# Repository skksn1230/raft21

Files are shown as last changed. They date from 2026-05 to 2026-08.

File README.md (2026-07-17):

# raft21（ソクタイプ型のDIYキーボード）
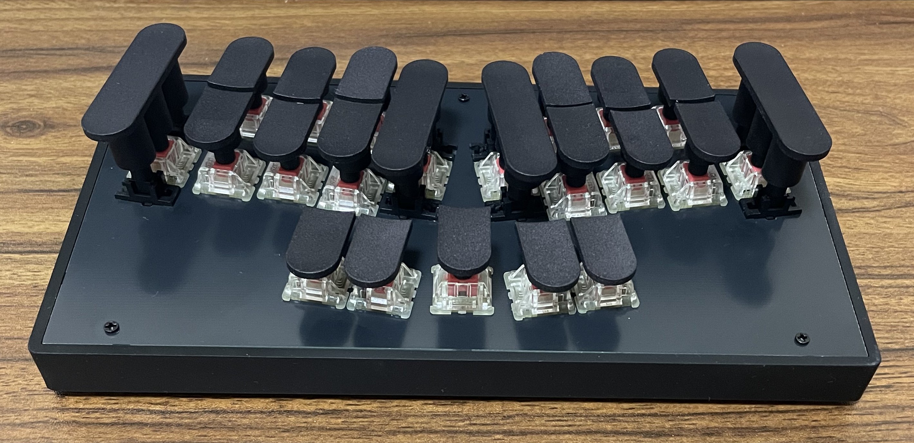
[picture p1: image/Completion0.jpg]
Completion

## 概要
raft21はStenturaプロトコル互換で動くソクタイプ型のDIYキーボードです。  
ソクタイプは21キーで、キーの配置やキーキャップのサイズ、表面のくぼみ、高低差があるなどの特徴があります。  
Ploverでの動作は確認できましたが、Stenturaプロトコルと同一のものではありません。  
実機などから情報を得てStenturaプロトコルを再現したということはありません。  
また、キーキャップのサイズなどに関して、ソクタイプの厳密な再現とは言えない可能性があります。  
## PCB基盤
KiCadを使用して作成。MCUはRP2040（Raspberry Pi Pico）を使用します。  
MCUはピンヘッダを使わない直接はんだ付け、基盤の厚さは1.6mm厚の前提でケースを設計しています。
## スイッチプレート
KiCadを使用して作成。基盤を発注するのと同様に発注します。1.6mm厚の前提でケースは作成しています。
## キーキャップ
ソクタイプ型のキーキャップを再現するために3Dプリンターで作成します。
（一番上の画像のキーキャップでは、JLC3DCPに発注した「PA12S-HP Nylon」という素材を使用しています。３Ｄプリンターの特性上、ステム（軸）のサイズが多少設計と異なる可能性があるため、弾力性のある素材を使用したいという意図もあり、ナイロン素材を採用しました。）
## ケース
3Dプリンターで作成します。`bottom-case.stl`
（一番上の画像のケースでは、JLC3DCPに発注した「JLC Black Resin」という素材を使用しています。一度、キーキャップと同じナイロン素材も試したことがありますが、反りが出てしまいました。「JLC Black Resin」では反りは出ませんでした）
## 製作に必要なもの（上記以外）
| 名称　　　　  | 個数　　　　  | 備考 　　　　 
|:---:|:---:|:---:|
| Raspberry Pi Pico  | 1 | Pico 2 ではない |
| PCBソケット  | 21 |スイッチを直接はんだ付けするなら不要|
| Cherry MX互換スイッチ  | 21 | 赤軸静音推奨　　　　 |
| プレートマウントスタビライザー 2U | 4 | MX用（PCBマウントではない） |
| M2 6mm ねじ | 14 | 天用・底用ねじ |
| M2 8mm スペーサー  | 7 | 外径4.0mm以下 |
| Micro USB ケーブル  | 1 | データ転送対応のもの |
| ゴム足 10mm  | 4 | 　高さ任意　　　 |

※PCBソケット（使用しないならキースイッチ）と Raspberry Pi PicoをPCB基盤にはんだ付けする必要があります。

※両手の人差し指側につけるスタビライザーは、接触する箇所があります。  
　適宜ニッパー等でカットし、接触しないようにする必要があります。
 静音フォームなども、キースイッチ間の距離が短いため、適宜加工する必要があるかもしれません。

※キースイッチとばねをルブ（潤滑）するなら、キースイッチ用とばね用の潤滑剤が必要です。

※キースイッチのばねを取り替えるなら、それも必要です。   
　23g 22mmは正常に動く中では軽い設定ですが、長期の使用に耐えるかは不明です。
 30g以上のほうが、安心して使えるかもしれません。

## uf2ファイル
BOOTSELボタンを押しながらUSBケーブルを接続し、Raspberry Pi Picoを書き込みモードで立ち上げ、そのフォルダ内にuf2ファイルをコピーすることで書き込みできます。

## 作業手順
- [大まかな作業手順](https://github.com/skksn1230/raft21/tree/main/image/README.md)  

## 参考
- [Plover](https://github.com/opensteno/plover)  
- [電子速記研究会 （はやとくんの会）](https://www.hayatokun.com/)
- [電子速記はやとくん](https://www.youtube.com/@%E9%9B%BB%E5%AD%90%E9%80%9F%E8%A8%98%E3%81%AF%E3%82%84%E3%81%A8%E3%81%8F%E3%82%93/shorts)

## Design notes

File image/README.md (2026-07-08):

### ソケットのはんだ付け
PCBの裏面に、ソケットをはんだ付けします。
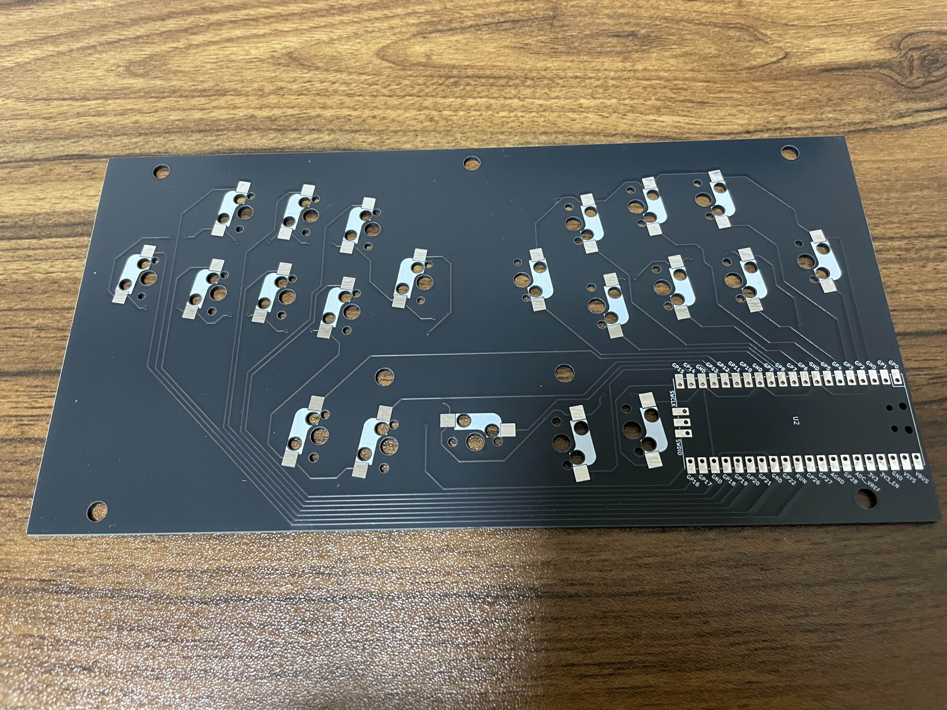
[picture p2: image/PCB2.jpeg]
PCB2

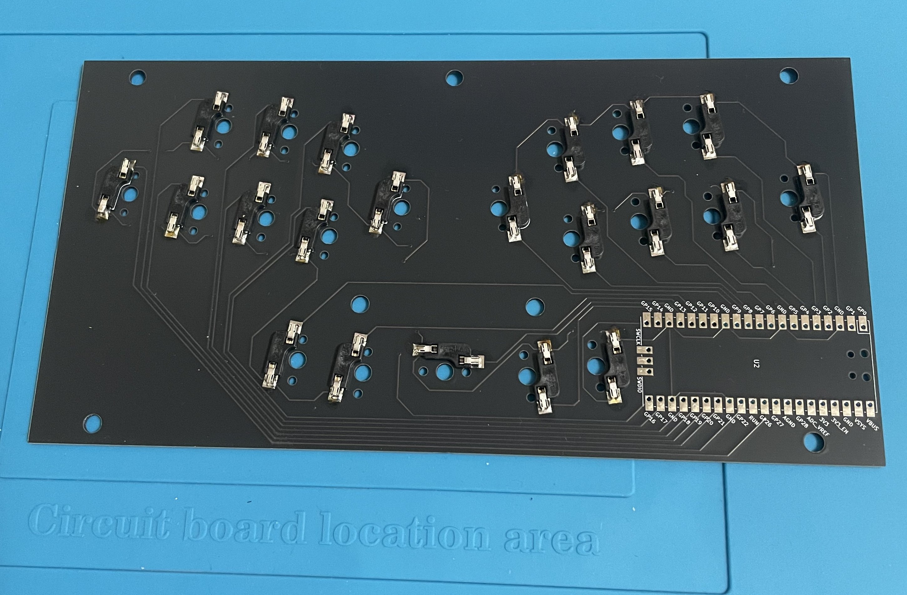
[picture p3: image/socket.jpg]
socket

### MCUのはんだ付け
３つの角を仮止め（図はピンヘッダを１つ折って使用している）して、４つ目の角をはんだ付けします。
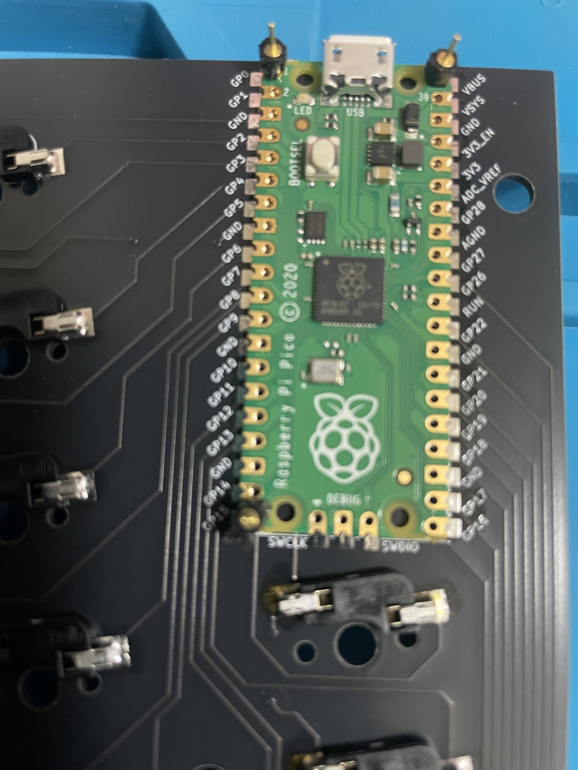
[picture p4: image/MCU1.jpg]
MCU1

１つの角（図では右下）をはんだ付けできたら、同様にほかの角もはんだ付けします。
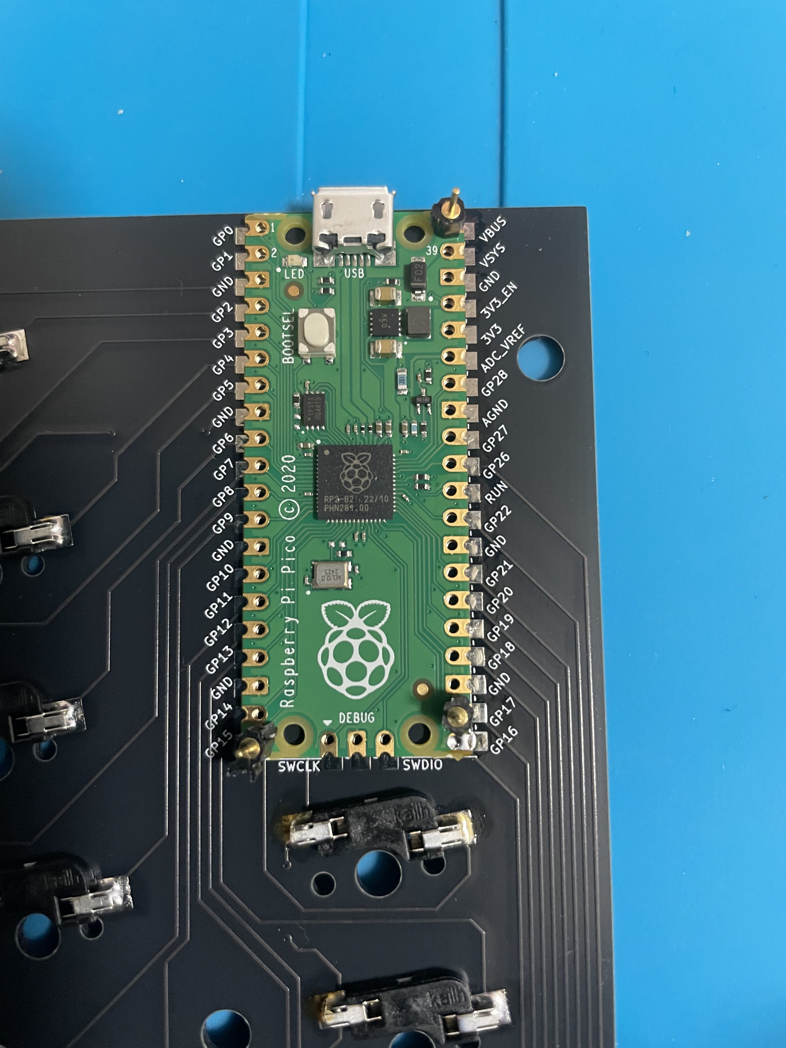
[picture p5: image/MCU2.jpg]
MCU2

４つの角だけはんだ付けできた状態。
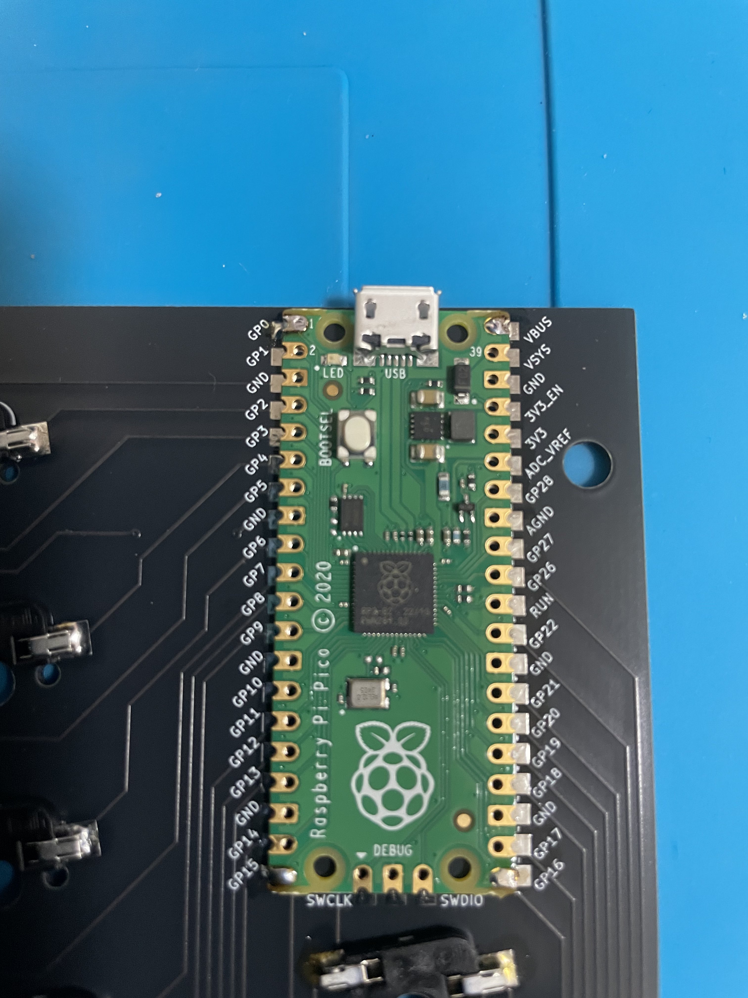
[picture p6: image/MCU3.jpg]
MCU3

四隅からちょっとずつはんだ付けしていきます。
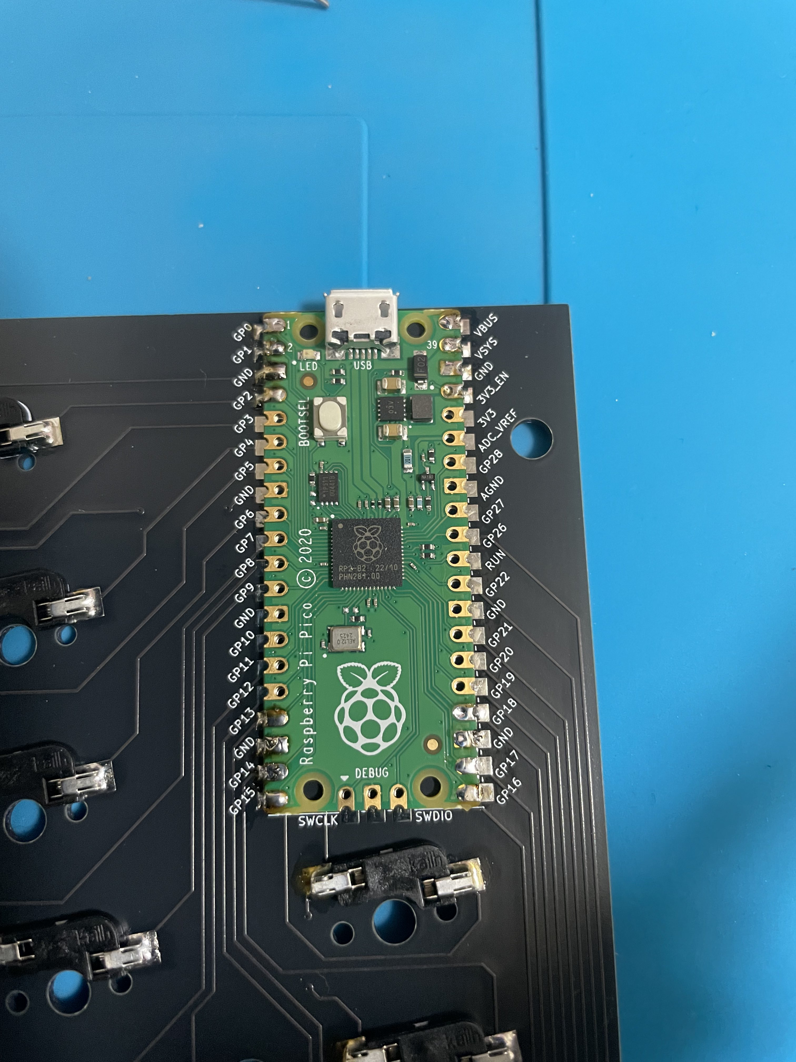
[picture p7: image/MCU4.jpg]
MCU4

すべてはんだ付けできた状態。
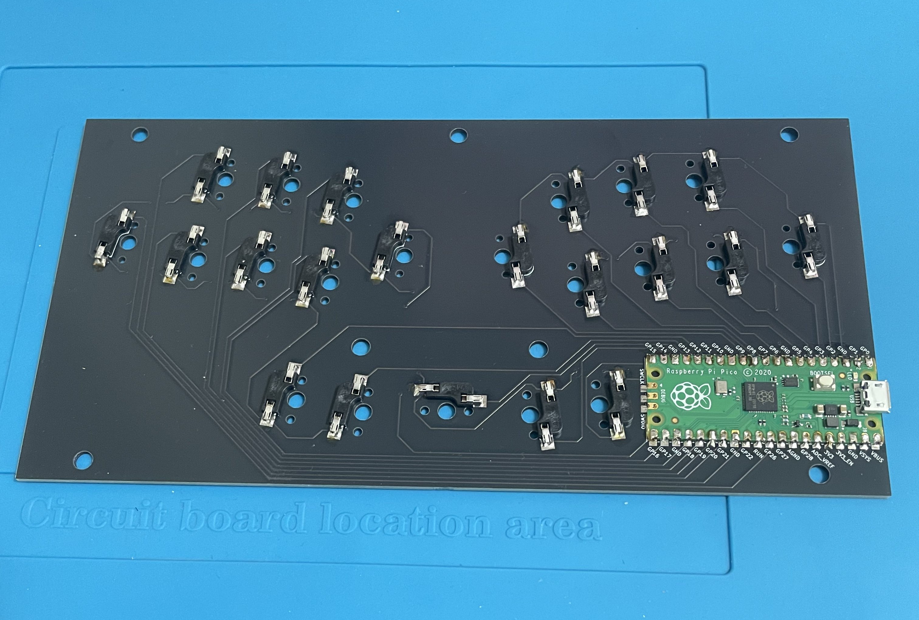
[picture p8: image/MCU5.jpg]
MCU5

### 静音シートの貼り付け（任意）
PCBの表面に、シートを貼っていきます。（図は右端に１つ貼った状態）
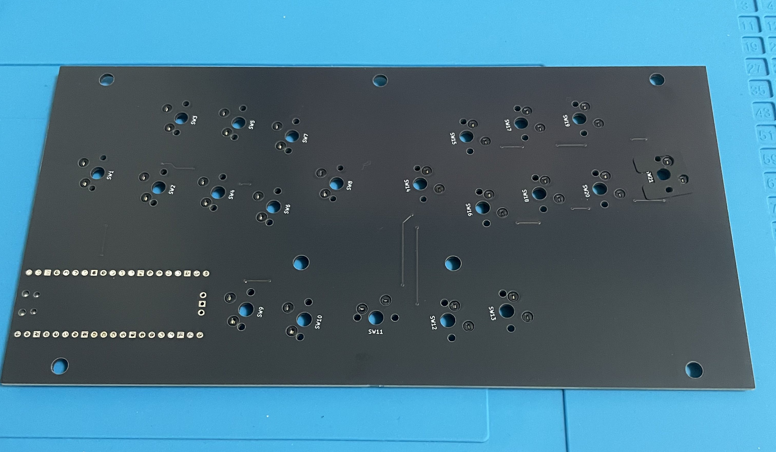
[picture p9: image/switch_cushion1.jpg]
switch cushion1

穴の部分を合わせて貼っていきます。
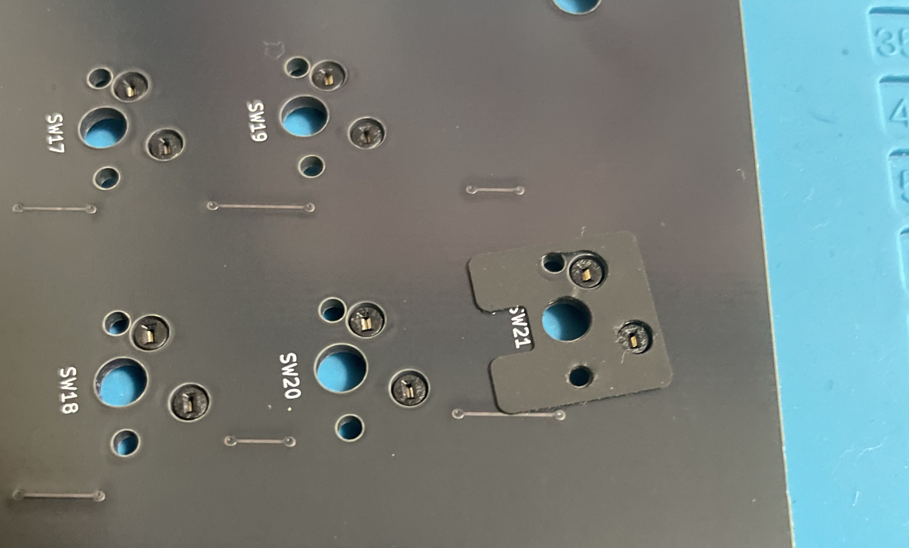
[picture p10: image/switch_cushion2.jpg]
switch cushion2

シートをすべて貼った状態。（右下１つはすでに静音フォームも貼った状態）
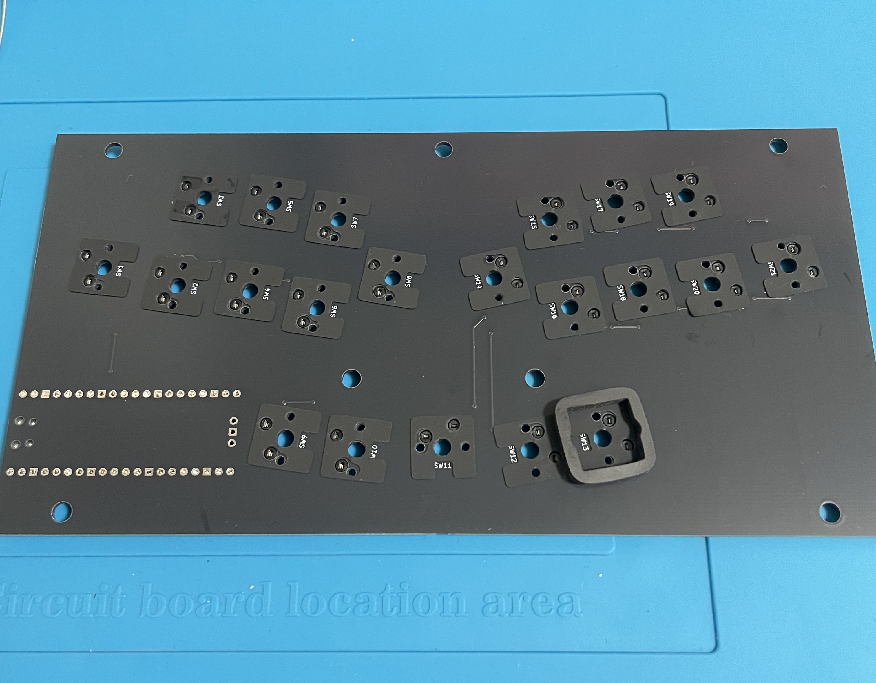
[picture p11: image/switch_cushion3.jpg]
switch cushion3

### 静音フォームの貼り付け（任意）
スイッチ間の距離がほとんどないため、静音フォームの４辺のうち１辺をカットしている箇所がほとんどです。また、スタビライザーを使用するスイッチには使用できません。その代わり、フォームを使用できないスイッチには、隣のスイッチのフォームが触れる状態にしたいため、その辺はカットしないようにしています。
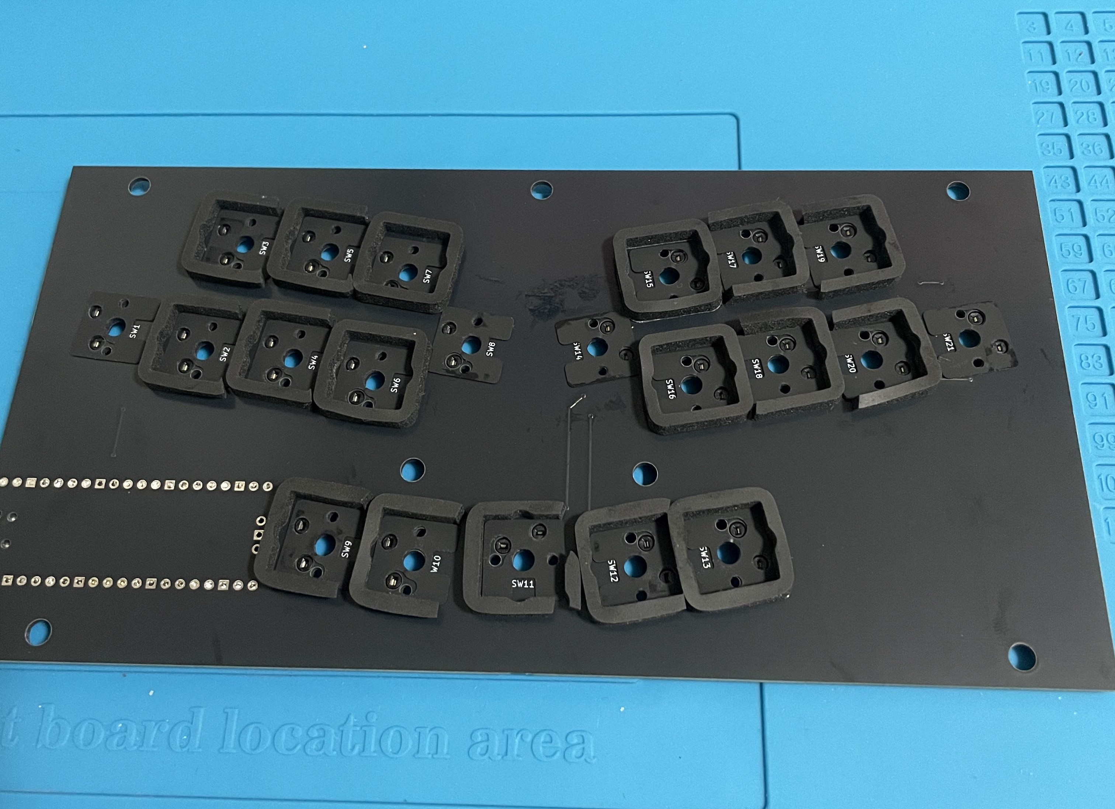
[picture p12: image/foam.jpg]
foam

### スタビライザーの加工・取り付け
人差し指側の２つは、前部分が接触し、キーの動きが悪くなるのでカットします。（カットしても多少はキーの重たさが増すかもしれません）
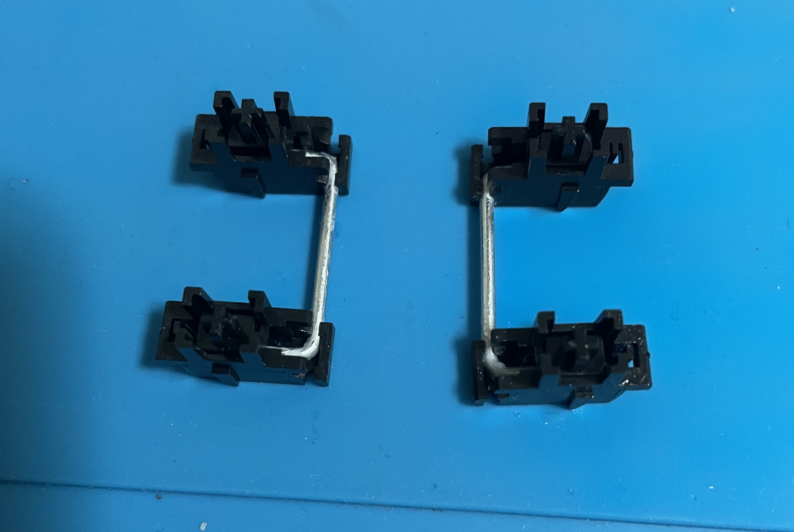
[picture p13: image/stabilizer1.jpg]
stabilizer1

ニッパーで前部分をカットした状態。
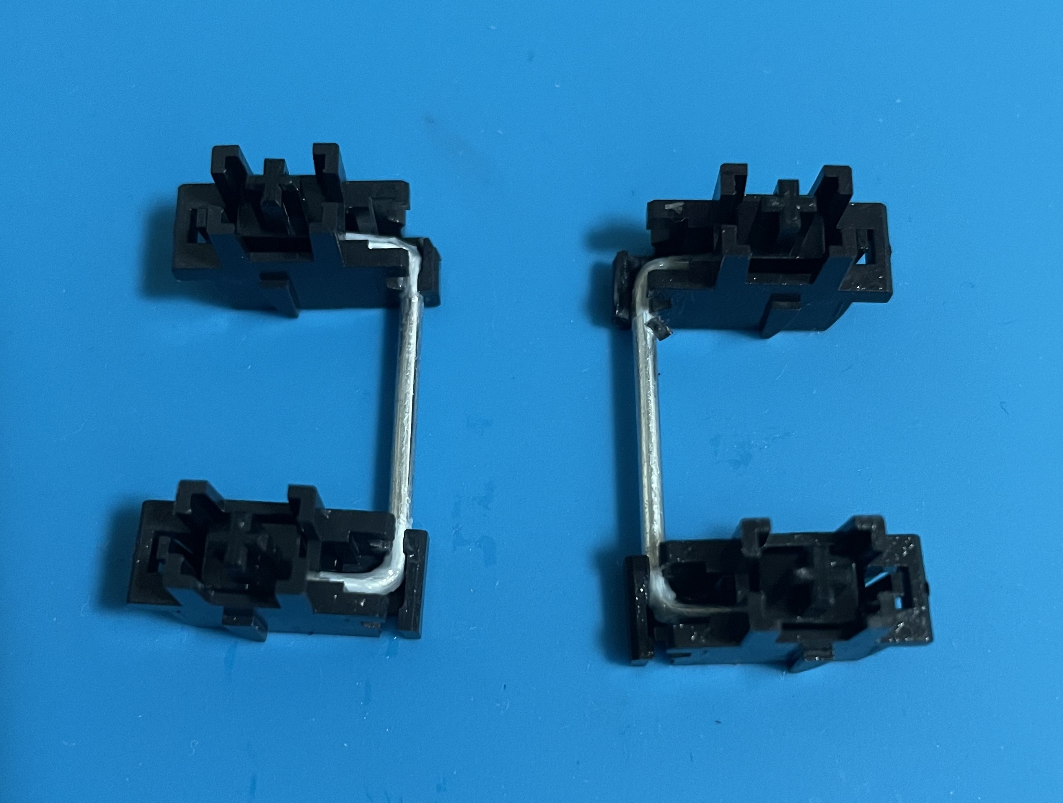
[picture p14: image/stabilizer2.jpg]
stabilizer2

４つのスタビライザーを取り付けます。
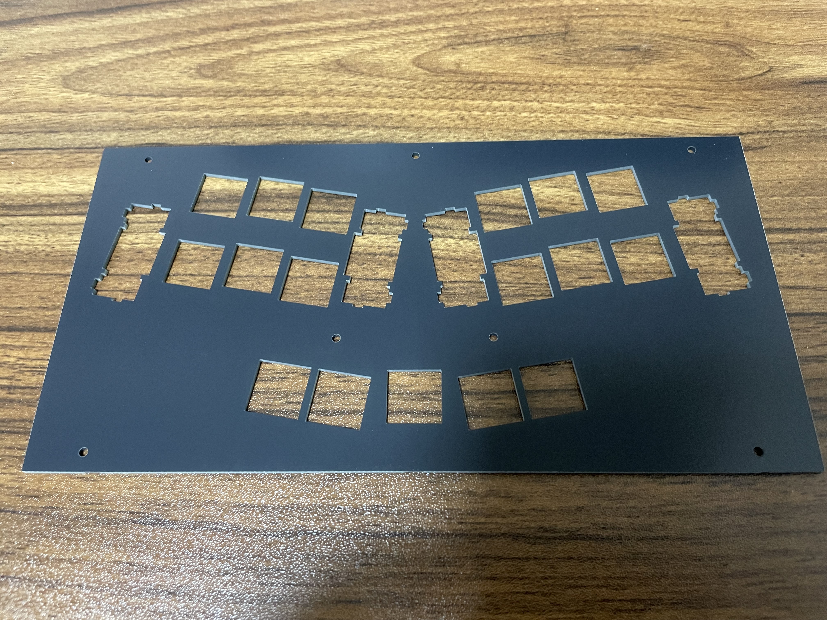
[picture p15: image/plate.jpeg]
plate

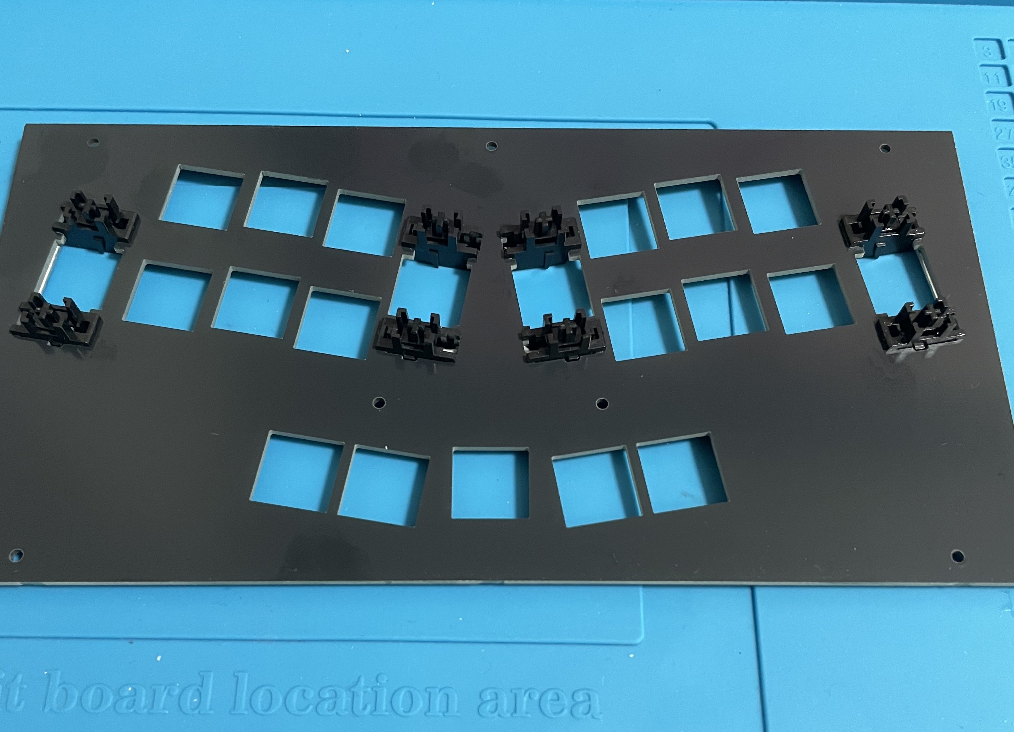
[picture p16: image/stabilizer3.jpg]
stabilizer3

### スイッチの取り付け
PCBの表面の上にスイッチプレートを重ね、その上からスイッチを差し込んでいきます。最初にいちばん外側と内側、スタビライザーのある箇所から差し込むとやりやすいと思います。あまり強く差し込もうとすると、ソケットの穴とずれている場合、スイッチのピンが曲がってしまいますので、慎重さが必要です。
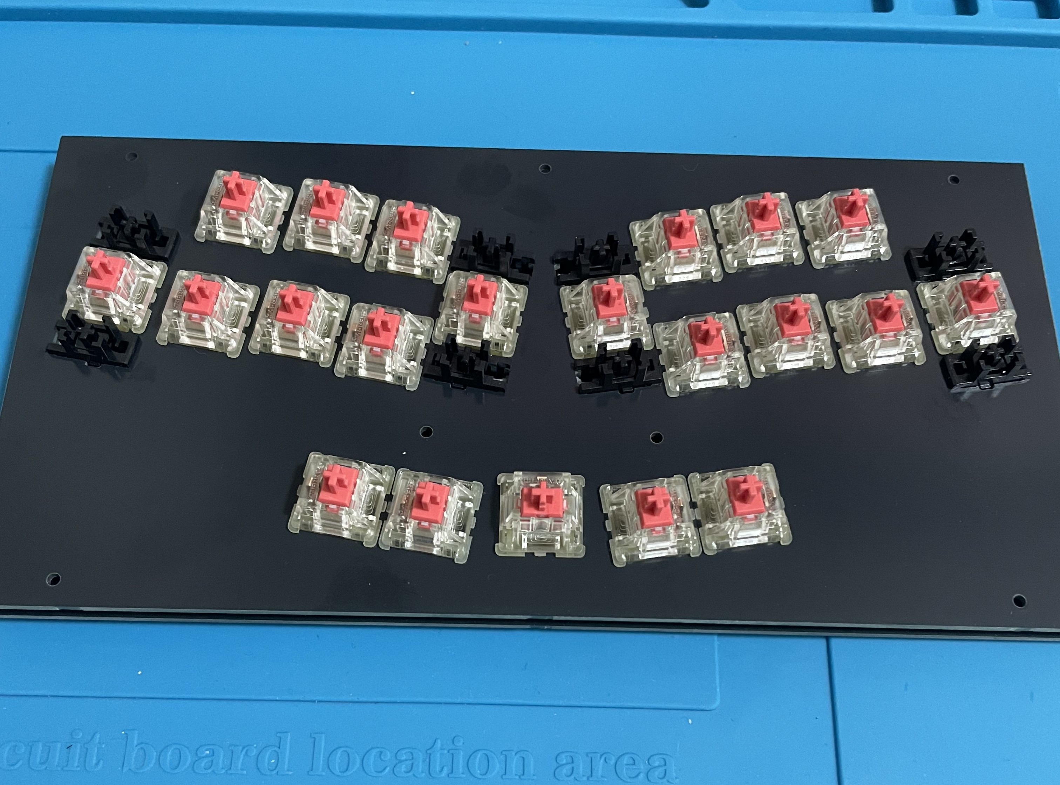
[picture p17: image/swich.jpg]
swich

### uf2ファイルの書き込みと、スイッチの動作確認
この時点でUSBケーブルを使ってPCと接続し、uf2ファイルを書き込んで、反訳用ソフトを使用して、１つ１つのスイッチを押して、ちゃんと反応しているかどうかを確かめます。はんだ付け不良の可能性、スイッチの不良の可能性などあります。（フリーのソフトとしては、ploverがあります。また日本では、はやとくんが有名です。符号を出力するのみのuf2ファイルを書き込んだ場合は、ソフトなしでもそれぞれのキーが反応するかどうか、メモ帳などのアプリでも確認することができます。）
### キーキャップの取り付け
下のキー４つ（中央のキー除く）と、内側のキー６つ（片側で長いキー１つ、短いキー２つ）は、キーの間隔を縮めるため、スイッチに差し込む軸の部分が中心より１mmずれています。それぞれが近づくように、キャップの軸のずれている側を確認しながら差し込みます。
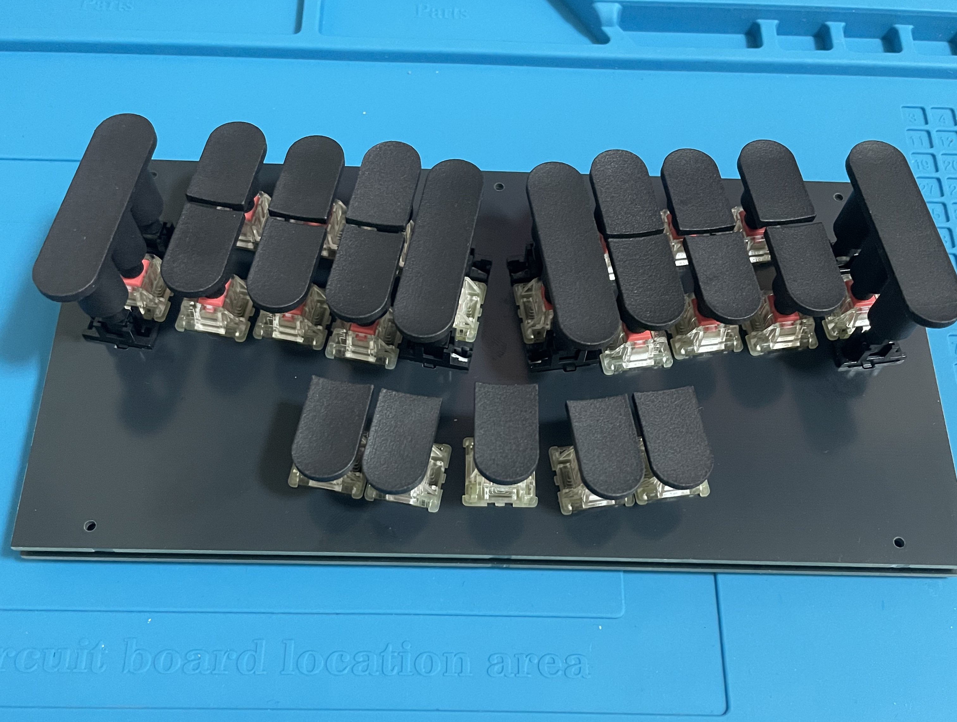
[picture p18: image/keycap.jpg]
keycap

### スペーサーの取り付け
ケースの底側からねじを締め、スペーサーを７か所ケースに取り付けます。
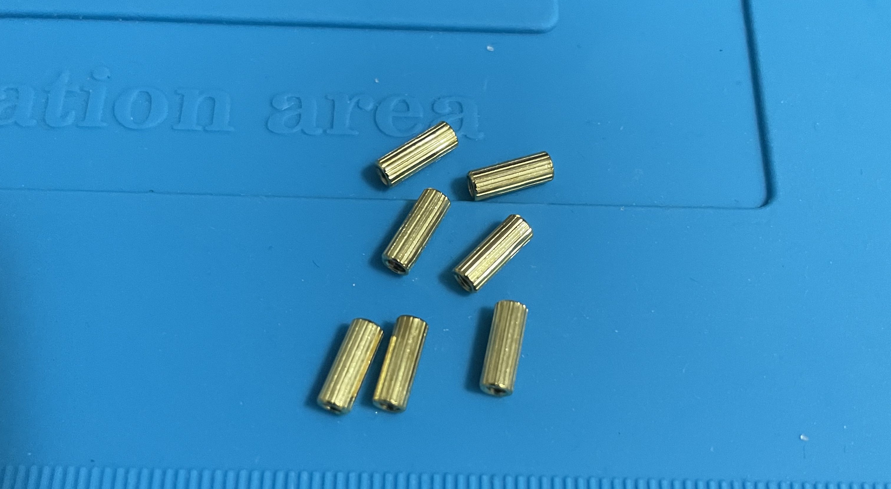
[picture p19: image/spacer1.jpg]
spacer1

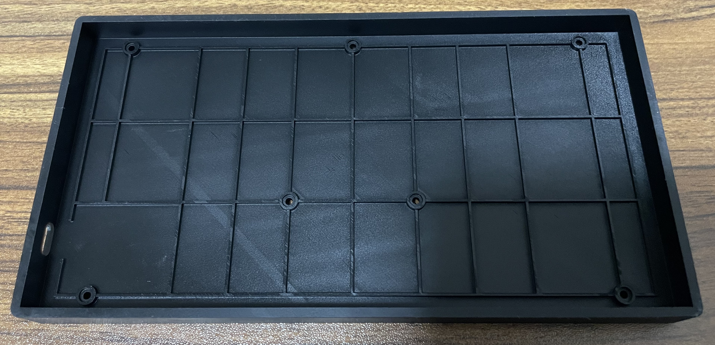
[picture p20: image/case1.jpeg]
case1

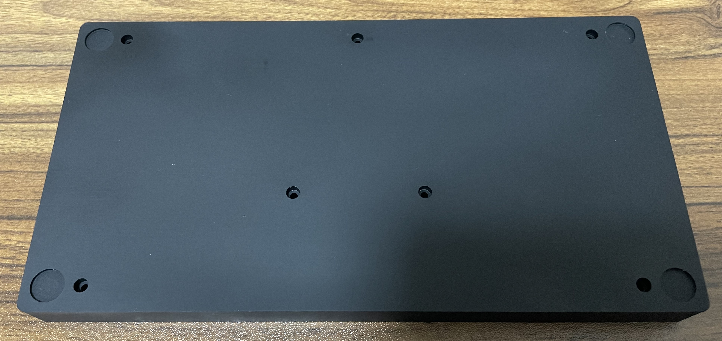
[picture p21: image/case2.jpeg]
case2

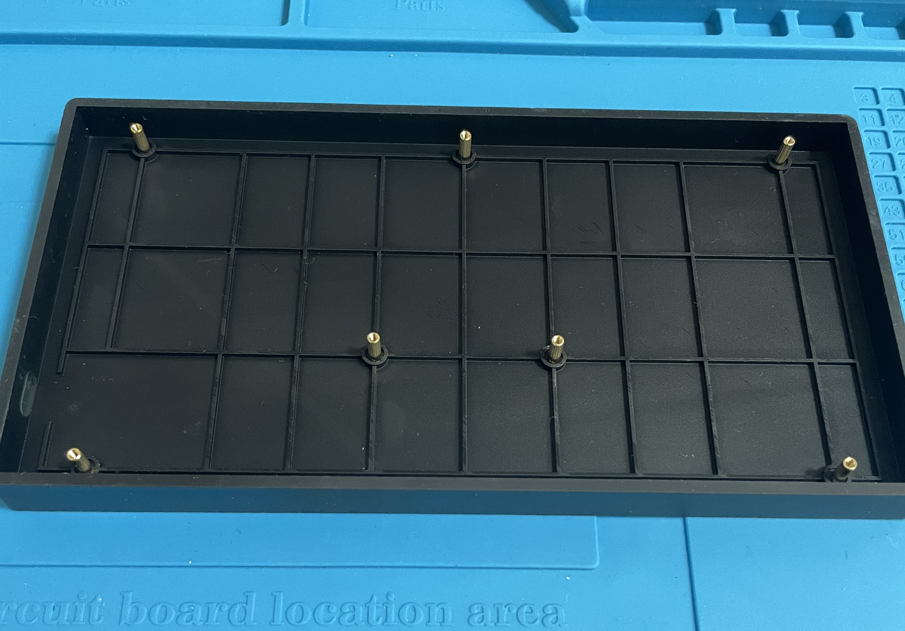
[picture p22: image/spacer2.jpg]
spacer2

### 本体をケースに入れて、スイッチプレートのねじを締める
左側のMCUのUSB差込口がひっかからないように、少しだけ先に入れる形でケースに入れ、上からねじで７か所締めます。
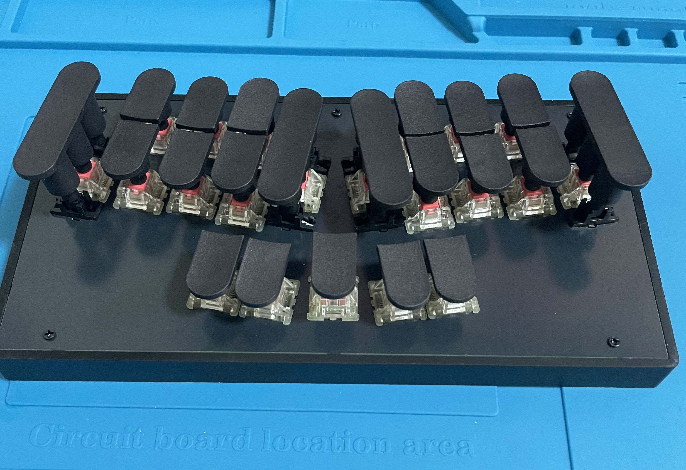
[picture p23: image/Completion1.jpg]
Completion1

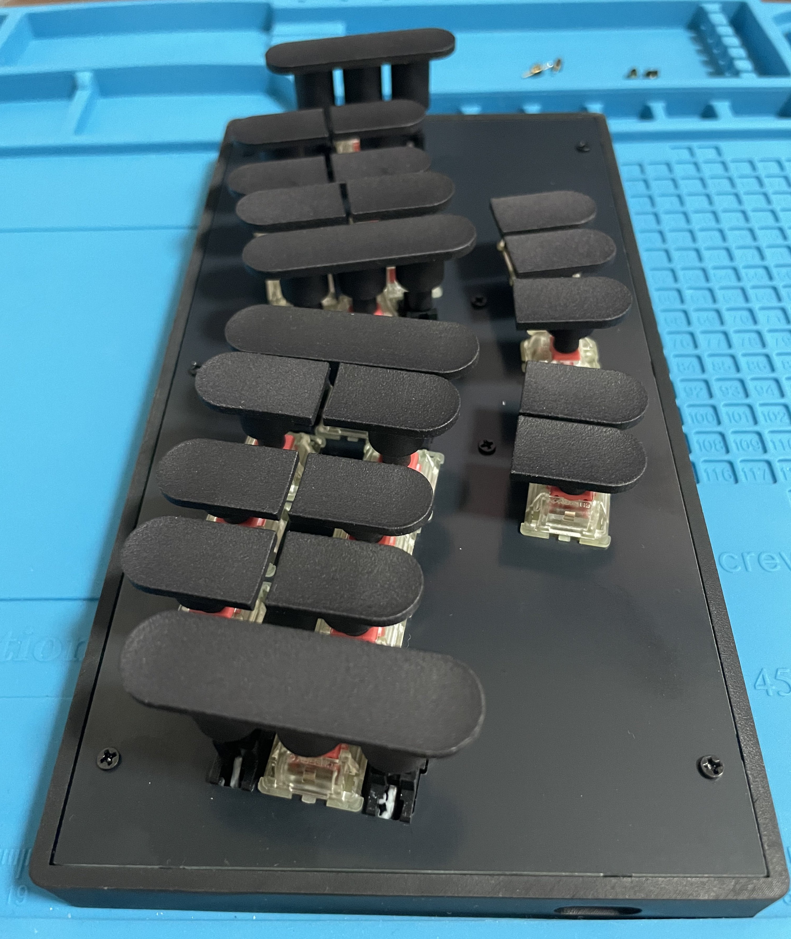
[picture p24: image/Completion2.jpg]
Completion2

### ゴム足の取り付け
ケースの底面の４か所にゴム足を貼ります。（接着剤など使用するほうが安心かもしれません）
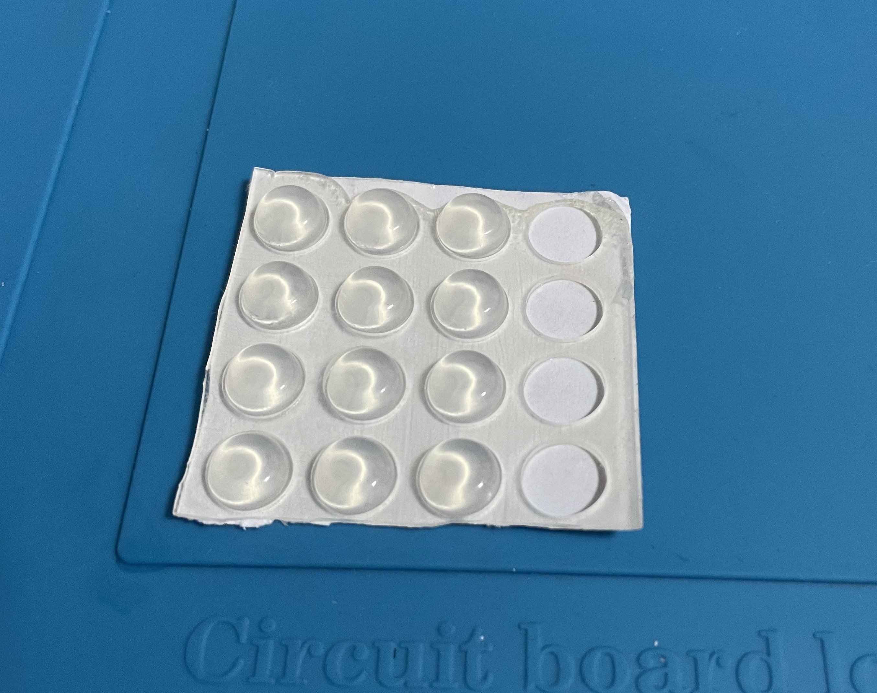
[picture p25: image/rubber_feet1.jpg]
rubber_feet1

rubber_feet2
### 完成
完成です！
Completion

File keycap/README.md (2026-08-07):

- ファイル名の末尾の数字が、raft21を１台作るのに必要な数です(合計21)。人差し指と親指で押すキー(＊を除く)は、キー間の距離を縮めるため、1mm中心からずれています。

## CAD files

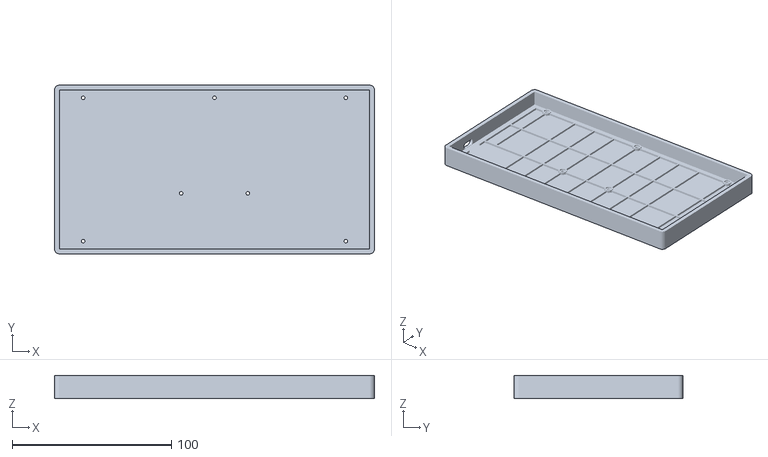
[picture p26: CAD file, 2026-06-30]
bottom-case.stl
201.0 x 106.0 x 14.6

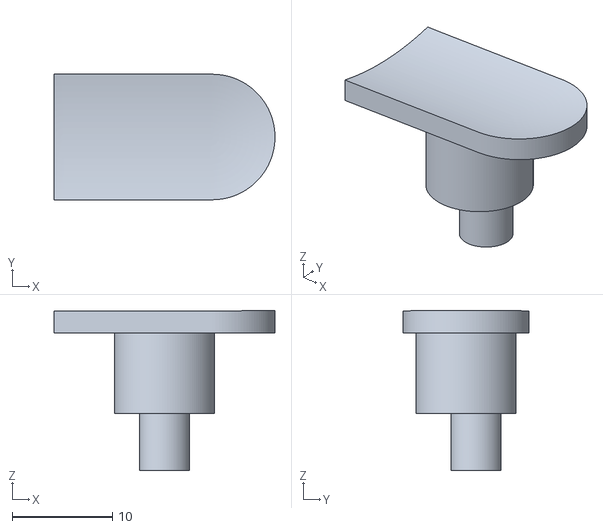
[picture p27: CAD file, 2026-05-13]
keycap/1u index finger2 2.stl
22.0 x 12.5 x 15.9

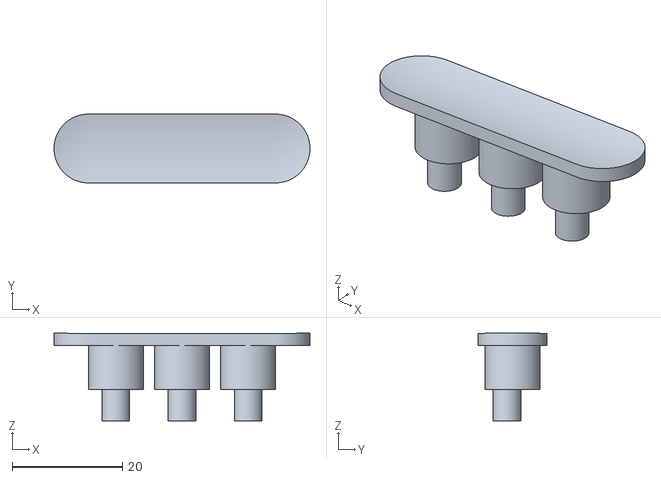
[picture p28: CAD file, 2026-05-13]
keycap/2u index finger 2.stl
46.5 x 12.5 x 15.9

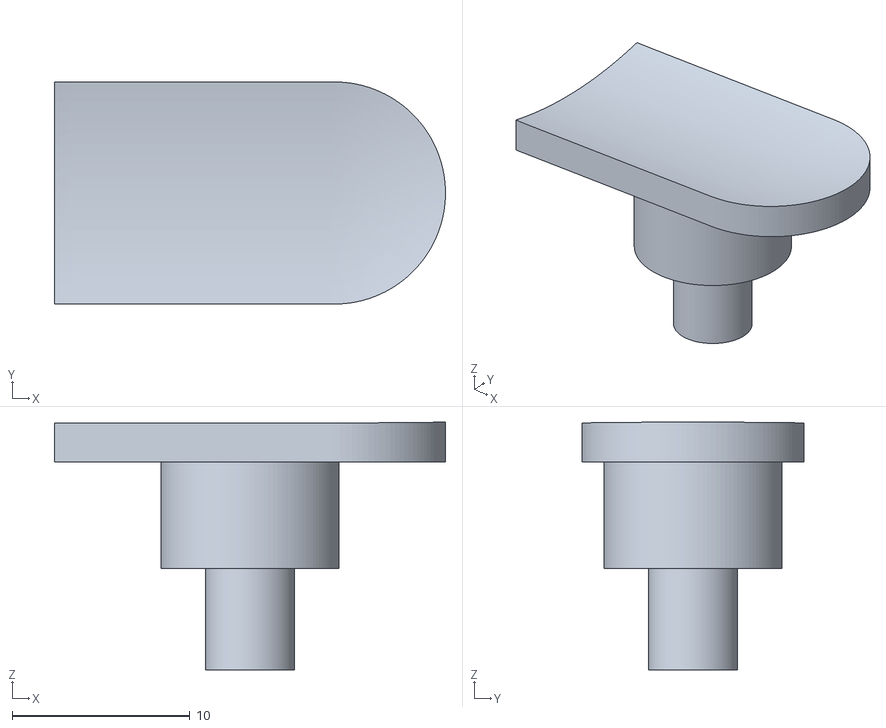
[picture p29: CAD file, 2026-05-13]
keycap/1u ring finger 4.stl
22.0 x 12.5 x 13.9

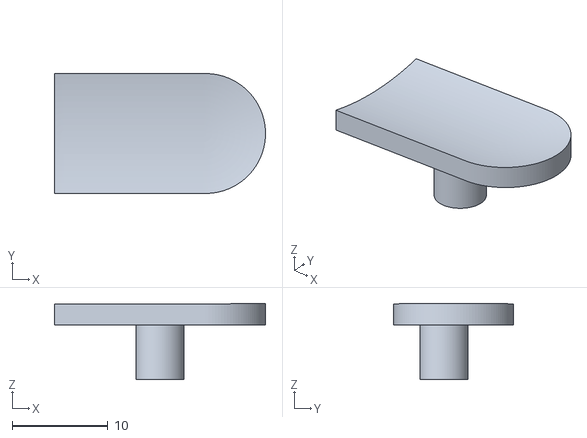
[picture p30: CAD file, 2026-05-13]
keycap/1u thumb1 2.stl
22.0 x 12.5 x 7.94

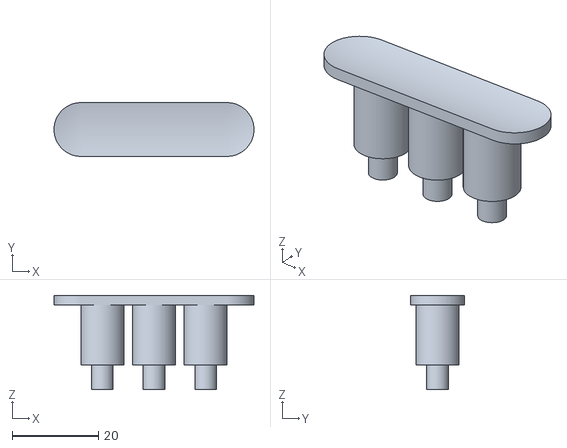
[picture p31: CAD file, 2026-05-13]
keycap/2u little finger 2.stl
46.5 x 12.5 x 21.9

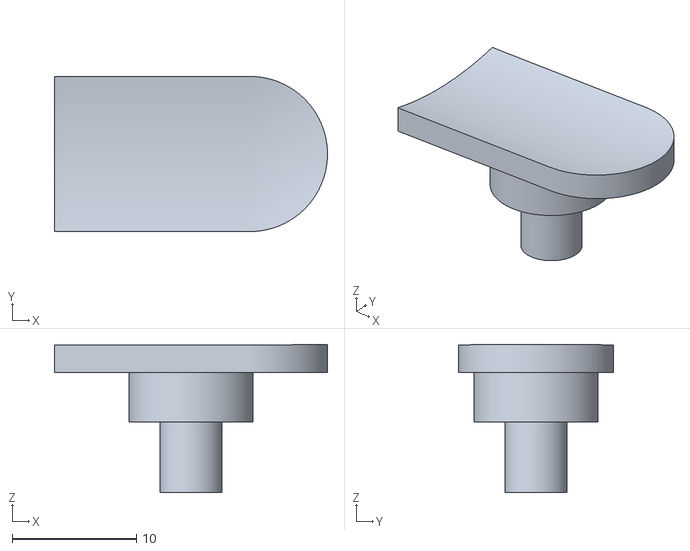
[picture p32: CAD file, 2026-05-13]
keycap/1u middle finger and star 5.stl
22.0 x 12.5 x 11.9

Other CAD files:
keycap/1u thumb2 2.stl
keycap/1u index finger1 2.stl

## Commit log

2026-07-08 Rename switch cushion1.jpg to switch_cushion1.jpg
2026-07-08 Rename switch cushion2.jpg to switch_cushion2.jpg
2026-07-08 Rename switch cushion3.jpg to switch_cushion3.jpg
